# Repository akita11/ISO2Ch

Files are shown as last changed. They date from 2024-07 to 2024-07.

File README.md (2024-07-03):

# ISO2ch

Chipanalog社のデジタルアイソレータ[CA-IS3642HW](https://www.lcsc.com/product-detail/Digital-Isolators-with-power_Chipanalog-CA-IS3642HW_C2890053.html)を使った2チャンネルのデジタルアイソレータです。電源と2本のデジタル信号線を電気的に絶縁（分離）することができます。使用しているCA-1364の仕様上、直流から150MHzまでのデジタル信号を伝送できます。

入出力はGroveコネクタで、出力側の電源電圧は5Vと3.3Vから選択でき、また2本のデジタル信号の向きを変更することができます。

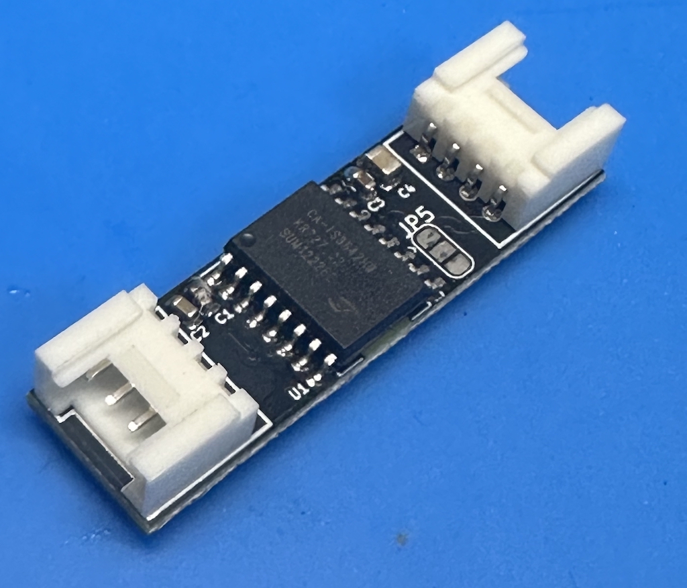
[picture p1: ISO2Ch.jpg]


## 基本的な使い方

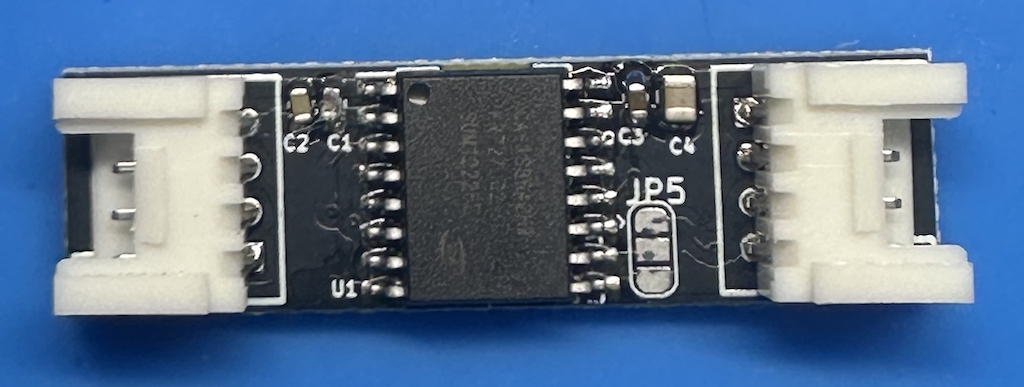
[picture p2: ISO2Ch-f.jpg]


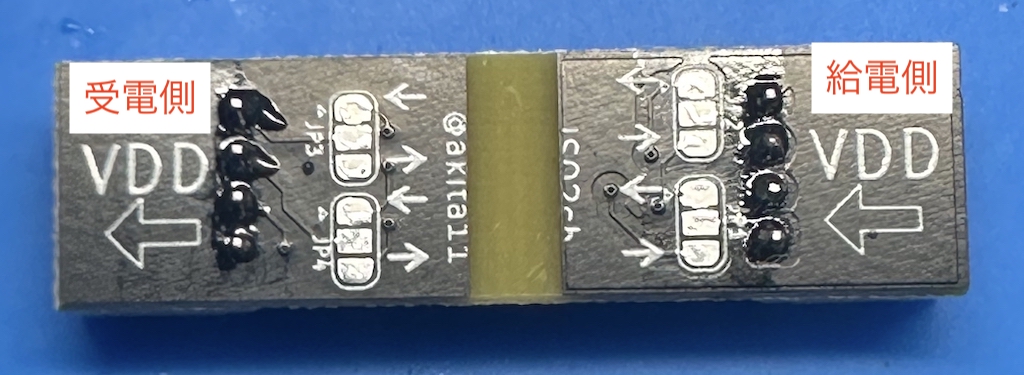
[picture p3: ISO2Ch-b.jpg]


裏面で、2つのGroveコネクタの種別を確認します。一方が電源の給電側、もう1方が電源の受電側です。
給電側のGroveコネクタに、電源を供給する側の機器（M5Stack等）を接続します。
受電側のGroveコネクタに、電源を受ける側の機器（センサ等）を接続します。受電側には5Vの電源（または3.3Vにも設定可能）が供給されます。

Groveコネクタの2本の信号線の信号（デジタル信号）の向きは、初期状態では2本とも「給電側＝入力／受電側＝出力」となっています。なお入力信号が未接続のときは出力側は"H"となります。（信号の向き後述のように半田ジャンパで変更できます）※仕様上、I2Cのように双方向の通信が必要な場合には使用できません

給電側・受電側のGroveコネクタのピン配置は以下のとおりです。

- 1: B (デジタル信号線1)
- 2: A (デジタル信号線2)
- 3: VDD
- 4: GND

## 設定変更の方法

### 受電側の電源電圧

表面のJP5で、受電側の電源電圧を設定できます。

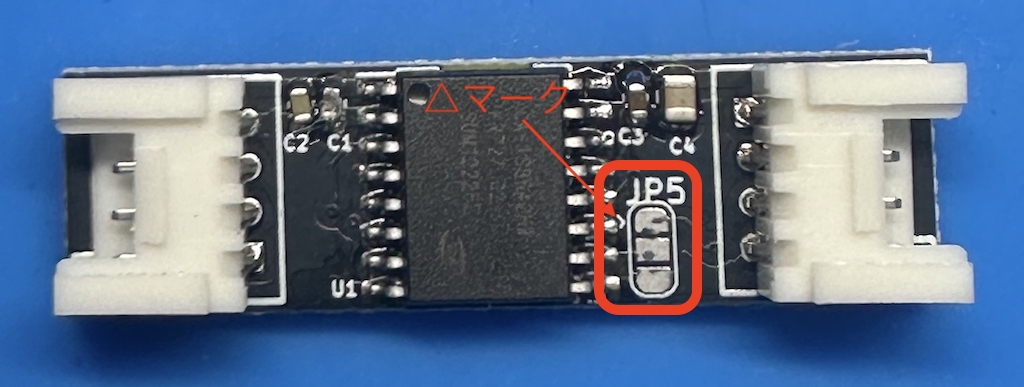
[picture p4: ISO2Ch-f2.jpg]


- 中央-△マークのある側をショート（初期状態）: 5V
- 中央-△マークのない側をショート: 3.3V （※中央-△マークのある側の基板パターンをカットしてください）

### デジタル信号の方向

裏面のJP1/2/3/4で、2本のデジタル信号線の信号の向きを設定できます。

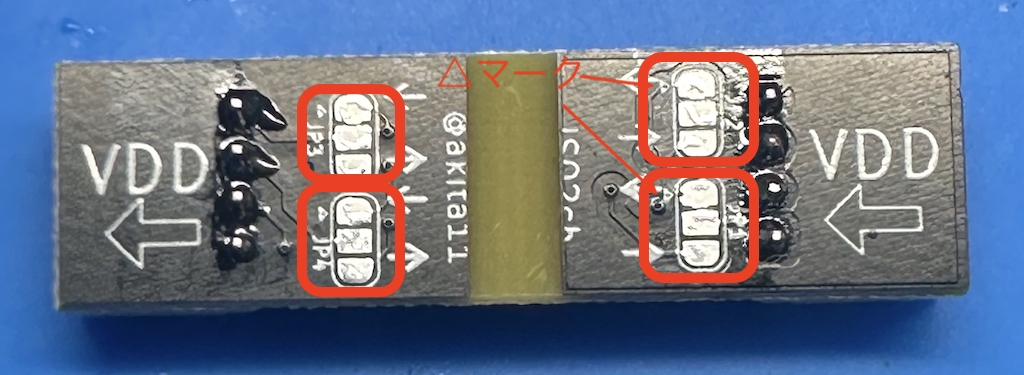
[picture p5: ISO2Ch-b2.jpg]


- B（デジタル信号線1）
 - JP1とJP4の中央-△マークのある側をショート（初期状態）：給電側＝入力、受電側＝出力
 - JP1とJP4の中央-△マークのない側をショート：給電側＝出力、受電側＝入力（※中央-△マークのある側の基板パターンをカットしてください）

- A（デジタル信号線2）
 - JP2とJP3の中央-△マークのある側をショート（初期状態）：給電側＝入力、受電側＝出力
 - JP2とJP3の中央-△マークのない側をショート：給電側＝出力、受電側＝入力（※中央-△マークのある側の基板パターンをカットしてください）

## Author

Junichi Akita (@akita11, akita@ifdl.jp)

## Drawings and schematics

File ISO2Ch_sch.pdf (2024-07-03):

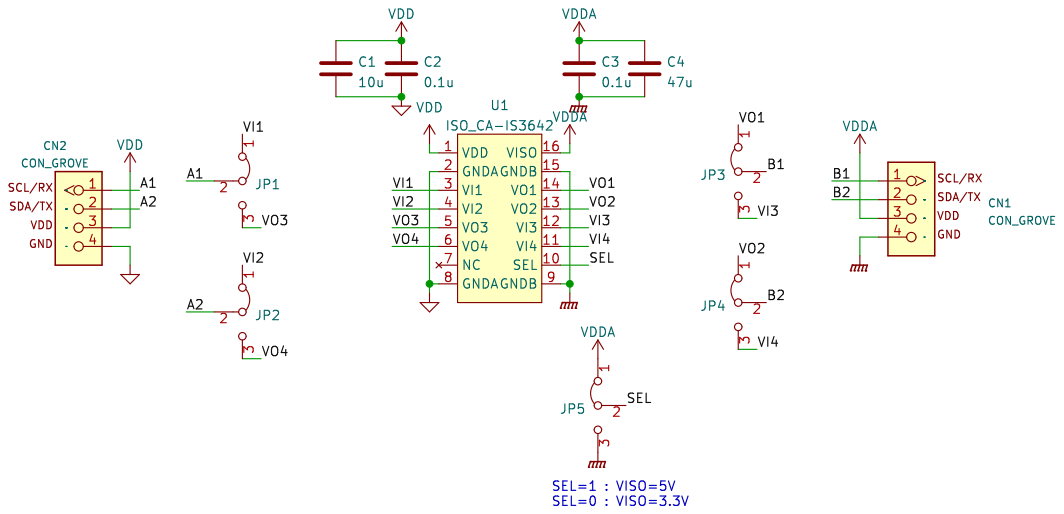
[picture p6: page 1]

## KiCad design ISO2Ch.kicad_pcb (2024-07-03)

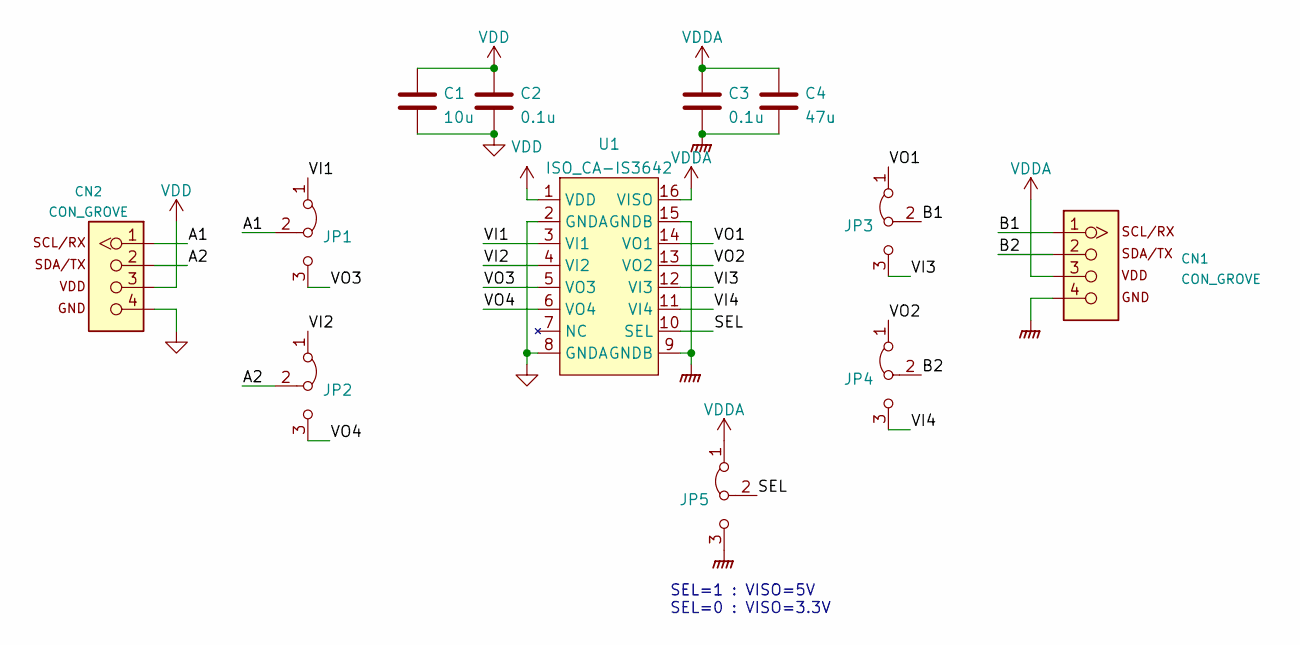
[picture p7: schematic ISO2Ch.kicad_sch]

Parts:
C1: 10u; C_0603_1608Metric; LCSC C109454
C2, C3: 0.1u; C_0603_1608Metric; LCSC C14663
C4: 47u; C_0805_2012Metric; LCSC C19103846
CN1, CN2: CON_GROVE; CON_GROVE_H
JP1, JP2, JP3, JP4, JP5: Jumper_3_Bridged12; SolderJumper-3_P1.3mm_Bridged12_RoundedPad1.0x1.5mm
U1: ISO_CA-IS3642; SOIC-16W_7.5x10.3mm_P1.27mm; LCSC C2890053

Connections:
/A1: CN2.1, JP1.2 (C)
/A2: CN2.2, JP2.2 (C)
/B1: CN1.1, JP3.2 (C)
/B2: CN1.2, JP4.2 (C)
/SEL: JP5.2 (C), U1.10 (SEL)
/VI1: JP1.1 (A), U1.3 (VI1)
/VI2: JP2.1 (A), U1.4 (VI2)
/VI3: JP3.3 (B), U1.12 (VI3)
/VI4: JP4.3 (B), U1.11 (VI4)
/VO1: JP3.1 (A), U1.14 (VO1)
/VO2: JP4.1 (A), U1.13 (VO2)
/VO3: JP1.3 (B), U1.5 (VO3)
/VO4: JP2.3 (B), U1.6 (VO4)
GND: C1.2, C2.2, CN2.4, U1.2 (GNDA), U1.8 (GNDA)
GNDPWR: C3.2, C4.2, CN1.4, JP5.3 (B), U1.9 (GNDB), U1.15 (GNDB)
VDD: C1.1, C2.1, CN2.3, U1.1 (VDD)
VDDA: C3.1, C4.1, CN1.3, JP5.1 (A), U1.16 (VISO)

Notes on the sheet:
SEL=1 : VISO=5V SEL=0 : VISO=3.3V

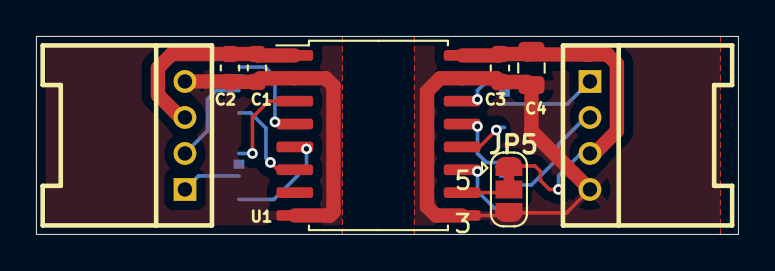
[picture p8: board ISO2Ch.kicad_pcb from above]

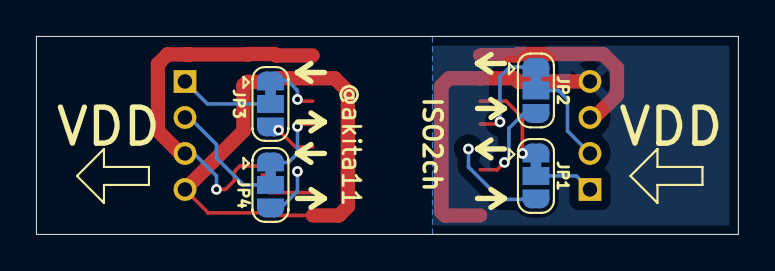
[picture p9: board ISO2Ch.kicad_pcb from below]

Board: 2 copper layers, 39.0 x 11.0 mm, 12 parts (4 on the bottom side), 17 nets.
